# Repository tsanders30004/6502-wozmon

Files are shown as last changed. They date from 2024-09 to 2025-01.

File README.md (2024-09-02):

# 6502 PCB Computer

## INTRODUCTION
- I was in highschool in the eighties when the *home computer revolution* introduced the world to computers running the MOS6502 and Z80 microprocessors.
- My first computer was an Atari 400 which used a 6502.
- When I added two numbers together in BASIC for the first time on that computer, I was hooked.   To this day, I am fascinated with computers.
- I couldn't help feeling nostalgic when I stumbled upon Ben Eater's excellent https://eater.net/6502 webpage, in which he describes how to build a 6502 computer on a breadboard.
- I quickly found out how difficult working with breadboards can be RE: unreliable connections, etc.  One loose wire was all it took to make the computer unusable.
- I therefore abandoned the breadboard altogether and instead decided to build a PCB.
- I had no idea how to do this; I could not even solder.  But I figured all of that out, and eventually I had a PCB that can run *HELLO WORLD* and *WOZMON*.
- This repository has all of the files necessary to build that PCB.

## PCB DESCRIPTION

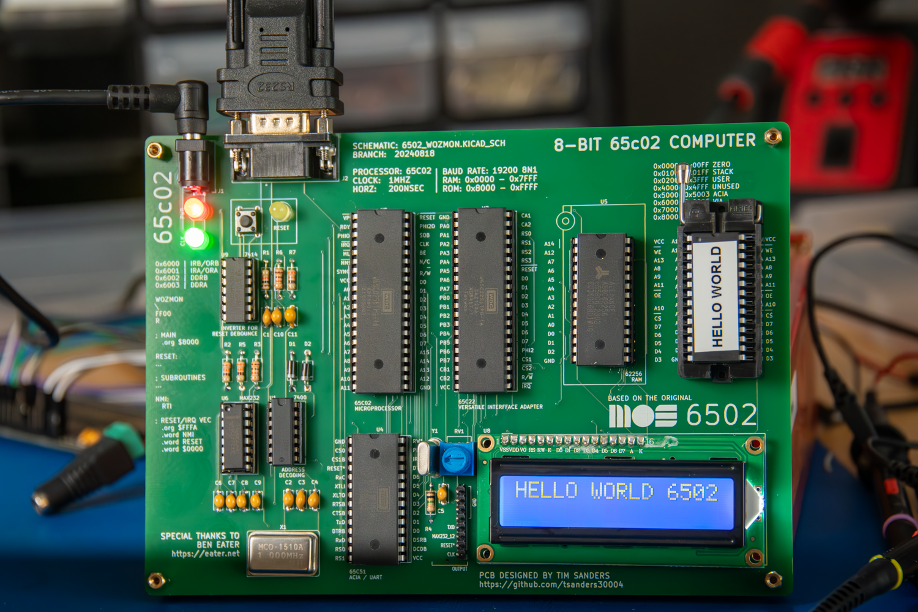
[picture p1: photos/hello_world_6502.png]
Hello World


|General Information||
|-|-|
|Microprocessor|WDC 65c02|
|I/O|65c22|
|UART|65c51|
|Clock|1MHz|
|ROM|32KB|
|RAM|32KB|
|Display|40x2 character LCD|
|Baud Rate|19200 8N1|

The upper left corner of the PCB has ports for +5V (barrel connector) and an RS-232 nine-pin serial cable.  
PWR and CLK LED's will illuminate when power and a clock signal (from the onboard 1MHz clock) are present, respectively.
The PCB can be reset via the RESET button directly below the RS-232 port.  The RESET LED will illuminate when the RESET button is pressed.

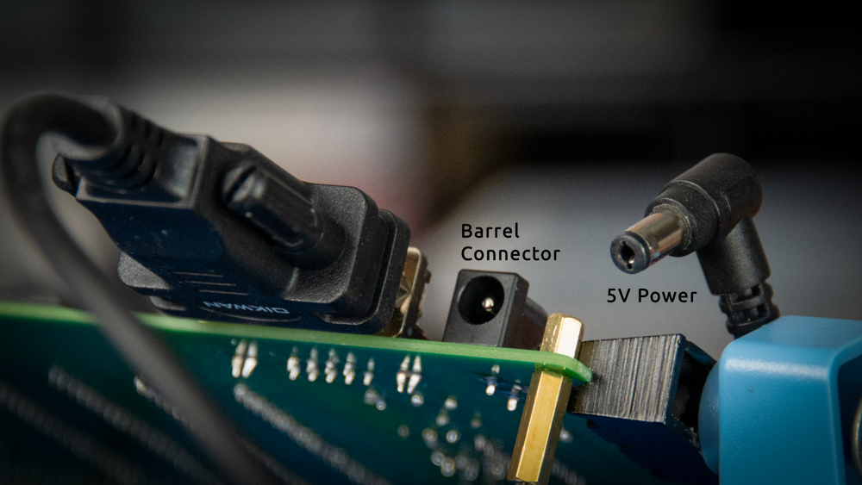
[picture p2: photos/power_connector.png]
Power Connectors


A column of output header pins is positioned immediately to the left of the LCD.  These output pins were primarily used for testing.  The top four pins are for GND.  (I used then when connecting the ground lead of an oscilloscope to the PCB.)  The bottom four pins are TxD, MAX232 pin 12, RESET*, and the CLOCK signal.  You can leave these pins unconnected if you don't want to use them.

## SOFTWARE 

|Filename|Description|
|-|-|
|software/hello/hello.s|'HELLO WORLD 6502' Assembly Code|
|software/hello/hello.out|'HELLO WORLD 6502' ROM file
|software/wozmon/wozmin.s|WOZMON Assembly Code|
|software/wozmon/wozmin.bin|WOZMON ROM file|

The computer *does not run the version of Microsoft BASIC* that Ben describes on his channel.  I have not figured (yet?) why that is so.  But it does run an alternate version of BASIC I found on Github.  See https://github.com/Fifty1Ford/BeEhBasic for more information.

## KICAD FILES

I used KiCad 6 to design the PCB.  
|Filename|Description|
|-|-|
|6502_wozmon.kicad_pro|KiCad 6 Project File|
|6502_wozmon.kicad_sch|KiCad 6 Schematic|
|6502_wozmon.kicad_pcb|KiCad 6 PCB File|
|6502_wozmon.csv|Bill of Materials|
|barrel_jack.pdf|Barrel Jack Power Connector|
|schematic.pdf|Schematic|
|photos/*.png|Photos|
|gerber/*|Gerber Files|

## CLOSING COMMENTS
- I am a hobbyist.  There are no doubt many ways to improve this design.  Feel free to do so! 
- I use a ZIF socket for the ROM chip to make it easier to remove.

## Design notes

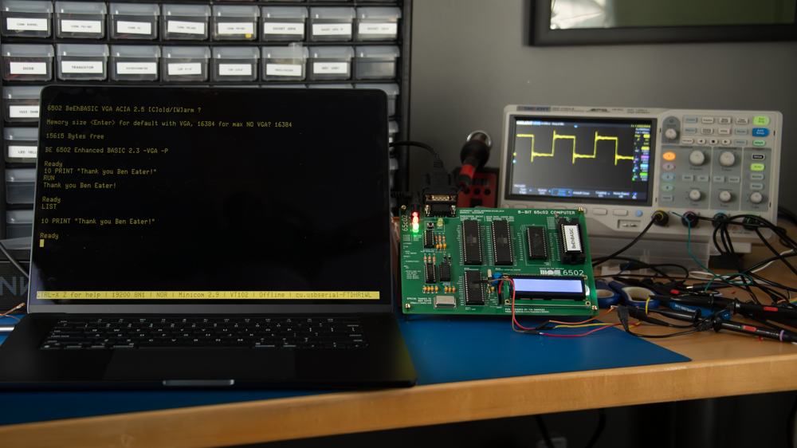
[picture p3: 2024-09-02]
photos/BeEhBASIC.png

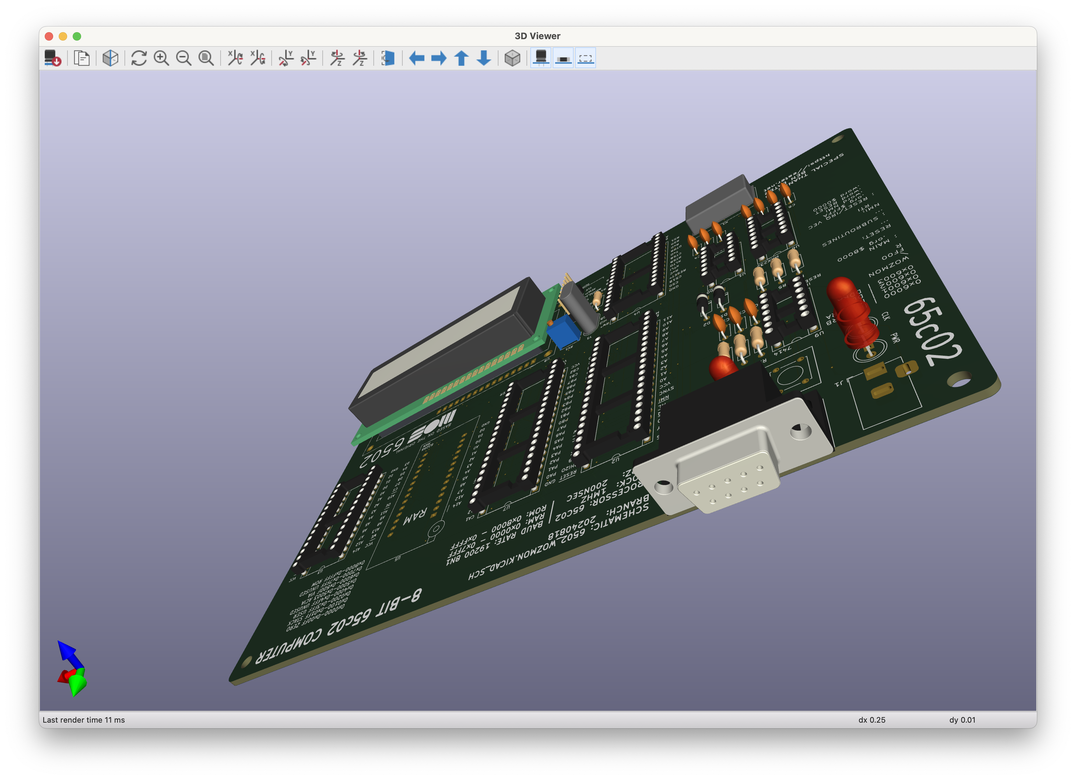
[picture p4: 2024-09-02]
photos/3d_2.png

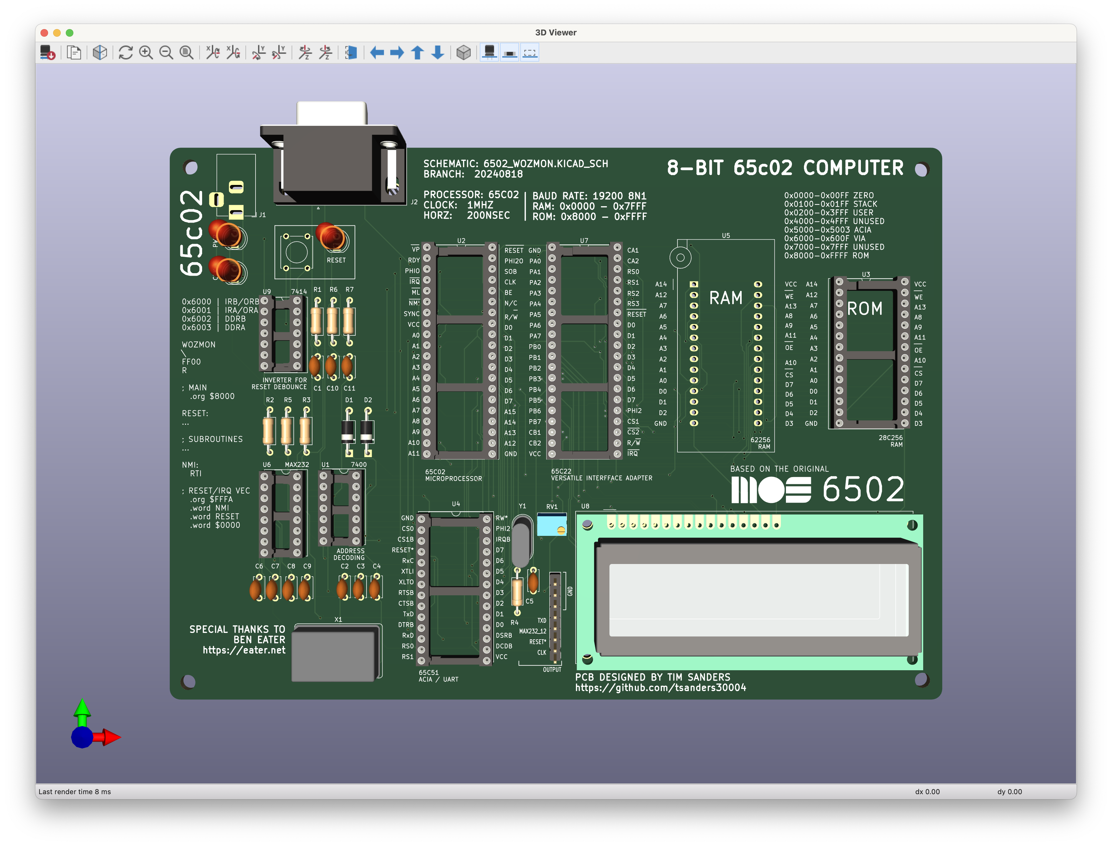
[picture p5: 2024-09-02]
photos/3d_1.png

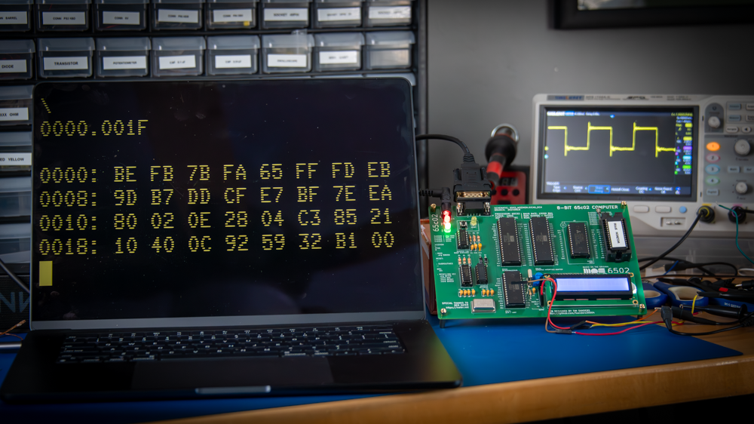
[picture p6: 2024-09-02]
photos/wozmon.png

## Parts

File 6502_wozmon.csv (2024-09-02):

Source: | /Users/tsanders/kicad/6502_wozmon/6502_wozmon.kicad_sch
Date: | 2024-01-21
Tool: | Eeschema (6.0.10-0)
Generator: | /Applications/KiCad/KiCad.app/Contents/SharedSupport/plugins/bom_csv_grouped_by_value_with_fp.py
Component Count: | 39
Ref | Qnty | Value | Cmp name | Footprint | Description | Vendor
C1, C2, C3, C4, C10, | 5 | 0.1u | C | Capacitor_THT:C_Disc_D5.0mm_W2.5mm_P5.00mm | Unpolarized capacitor
C5, | 1 | 20pf | C | Capacitor_THT:C_Disc_D5.0mm_W2.5mm_P5.00mm | Unpolarized capacitor
C6, C7, C8, C9, | 4 | 1uF | C | Capacitor_THT:C_Disc_D5.0mm_W2.5mm_P5.00mm | Unpolarized capacitor
C11, | 1 | 10u | C | Capacitor_THT:C_Disc_D5.0mm_W2.5mm_P5.00mm | Unpolarized capacitor
D1, D2, | 2 | D | D | Diode_THT:D_A-405_P10.16mm_Horizontal | Diode
D3, | 1 | LED | LED | LED_THT:LED_D5.0mm | Light emitting diode
J1, | 1 | Barrel_Jack_Switch_Pin3Ring | Barrel_Jack_Switch_Pin3Ring | Connector_BarrelJack:BarrelJack_Horizontal | DC Barrel Jack with an internal switch
J2, | 1 | DB9_Female | DB9_Female | Connector_Dsub:DSUB-9_Female_Horizontal_P2.77x2.84mm_EdgePinOffset9.90mm_Housed_MountingHolesOffset11.32mm | 9-pin female D-SUB connector
J4, | 1 | Conn_01x08_Male | Conn_01x08_Male | Connector_PinHeader_2.54mm:PinHeader_1x08_P2.54mm_Vertical | Generic connector, single row, 01x08, script generated (kicad-library-utils/schlib/autogen/connector/)
LED_1, LED_2, | 2 | LED | LED | LED_THT:LED_D5.0mm | Light emitting diode
R1, | 1 | 10K | R | Resistor_THT:R_Axial_DIN0207_L6.3mm_D2.5mm_P10.16mm_Horizontal | Resistor
R2, R5, | 2 | 220 | R | Resistor_THT:R_Axial_DIN0207_L6.3mm_D2.5mm_P10.16mm_Horizontal | Resistor
R3, R6, | 2 | 1K | R | Resistor_THT:R_Axial_DIN0207_L6.3mm_D2.5mm_P10.16mm_Horizontal | Resistor
R4, | 1 | 1M | R | Resistor_THT:R_Axial_DIN0207_L6.3mm_D2.5mm_P10.16mm_Horizontal | Resistor
R7, | 1 | 330 | R | Resistor_THT:R_Axial_DIN0207_L6.3mm_D2.5mm_P10.16mm_Horizontal | Resistor
RV1, | 1 | R_Potentiometer | R_Potentiometer | Potentiometer_THT:Potentiometer_Bourns_3266Y_Vertical | Potentiometer
SW2, | 1 | SW_Push_Dual | SW_Push_Dual | Button_Switch_THT:SW_Tactile_Straight_KSA0Axx1LFTR | Push button switch, generic, symbol, four pins
U1, | 1 | 7400 | 7400 | Package_DIP:DIP-14_W7.62mm_Socket | quad 2-input NAND gate
U2, | 1 | W65C02 | W65C02SxP | Package_DIP:DIP-40_W15.24mm_Socket | W65C02S 8-bit CMOS General Purpose Microprocessor, DIP-40
U3, | 1 | 28C256 | 28C256 | Package_DIP:DIP-28_W15.24mm_Socket | Paged Parallel EEPROM 256Kb (32K x 8), DIP-28/SOIC-28
U4, | 1 | W65C51N | W65C51NxP | Package_DIP:DIP-28_W15.24mm_Socket | W65C51N CMOS Asynchronous Communication Interface Adapter (ACIA), Serial UART, DIP-28
U5, | 1 | 62256 | CY62256-70PC | Socket:DIP_Socket-28_W11.9_W12.7_W15.24_W17.78_W18.5_3M_228-1277-00-0602J | 256K (32K x 8) Static RAM, 70ns, DIP-28
U6, | 1 | MAX232 | MAX232 | Package_DIP:DIP-16_W7.62mm_Socket | Dual RS232 driver/receiver, 5V supply, 120kb/s, 0C-70C
U7, | 1 | 65C22 | W65C22SxP | Package_DIP:DIP-40_W15.24mm_Socket | W65C22S CMOS Versatile Interface Adapter (VIA), 20-pin I/O, 2 Timer/Counters, DIP-40
U8, | 1 | WC1602A | WC1602A | Display:WC1602A | LCD 16x2 Alphanumeric , 8 bit parallel bus, 5V VDD
U9, | 1 | 74HC14 | 74HC14 | Package_DIP:DIP-14_W7.62mm_Socket | Hex inverter schmitt trigger
X1, | 1 | GTXO-S14V | GTXO-S14V | Oscillator:Oscillator_DIP-14 | 3.3 & 5V Stratum 3 Sinewave TCXO, DIP14-style metal package
Y1, | 1 | 1.8432MHZ | Crystal | Crystal:Crystal_HC18-U_Vertical | Two pin crystal

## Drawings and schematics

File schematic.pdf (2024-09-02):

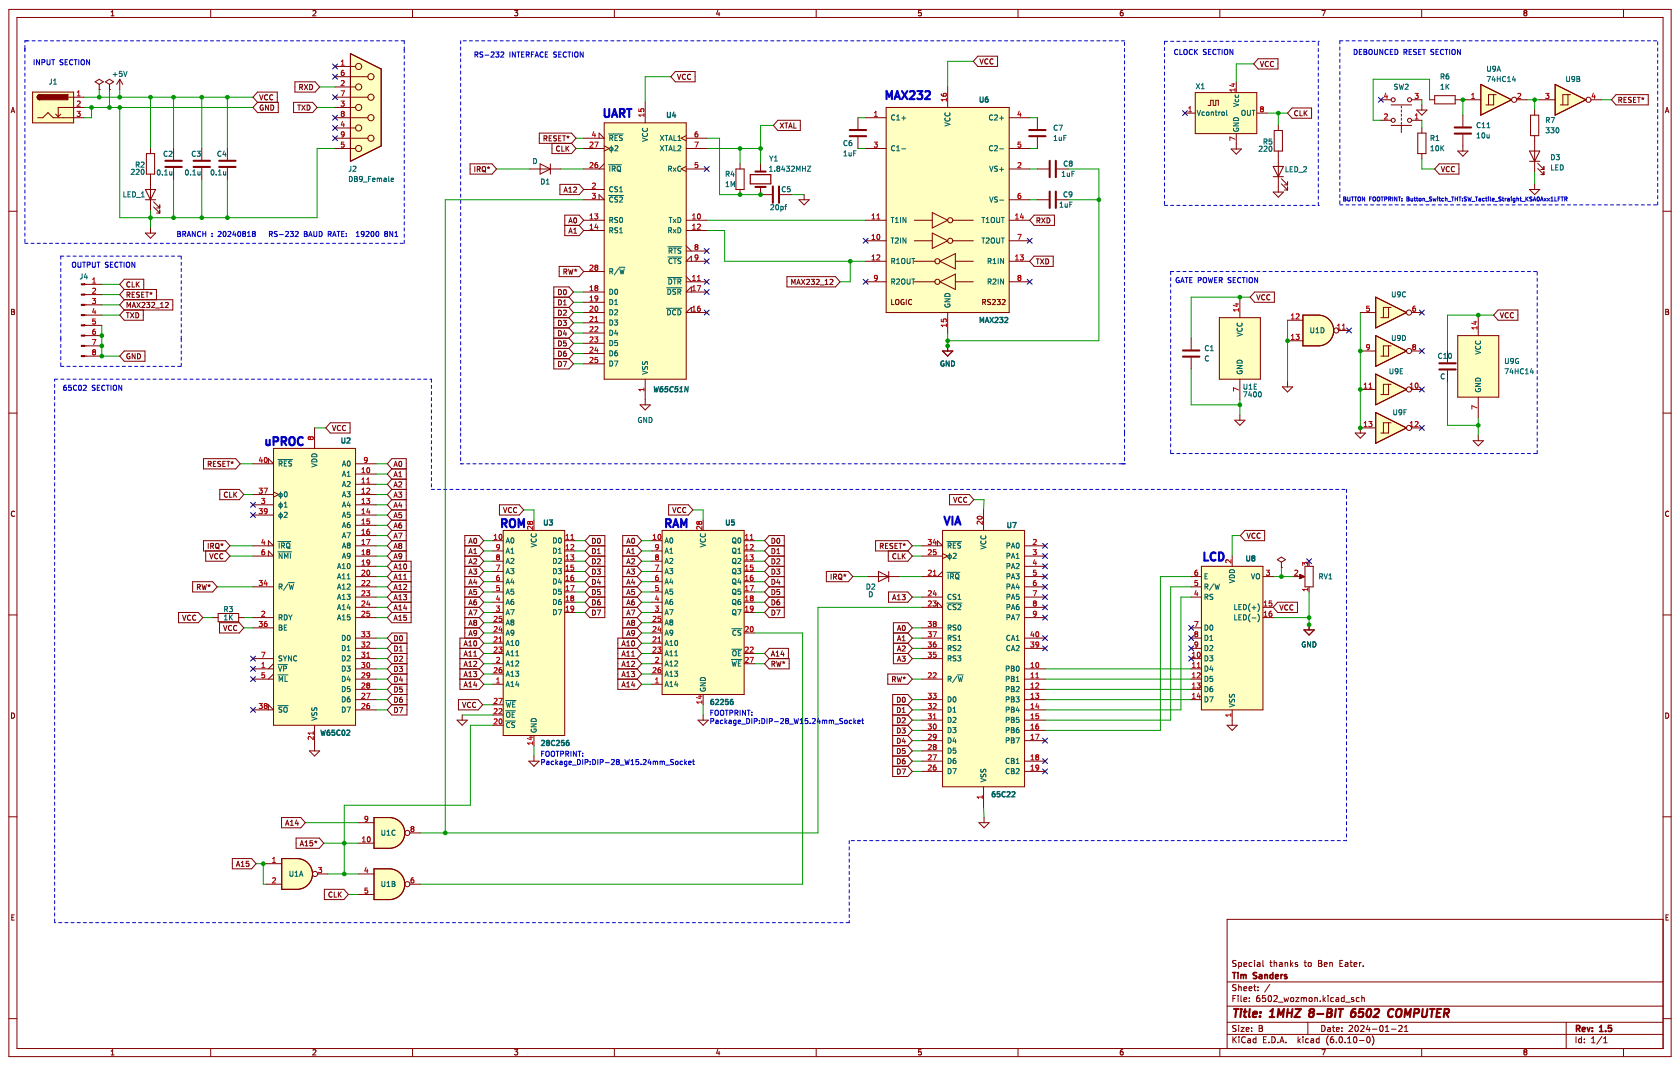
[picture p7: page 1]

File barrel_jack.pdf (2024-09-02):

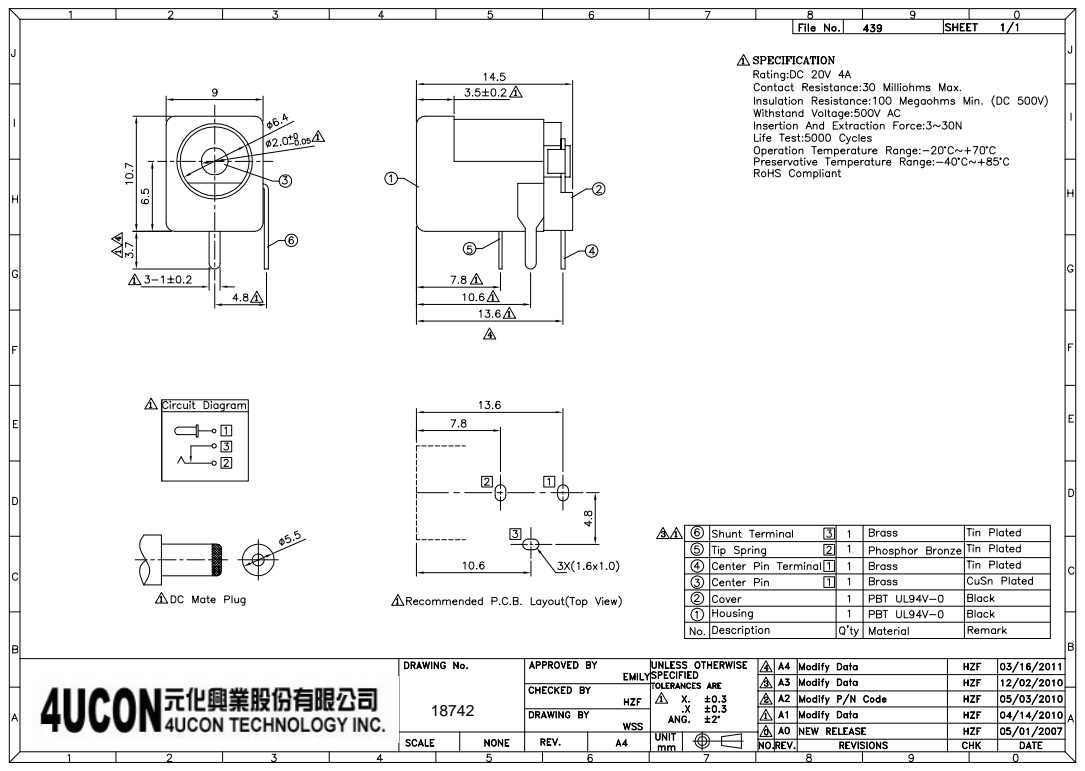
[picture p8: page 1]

## Mouser Electronics

Authorized Distributor

Click to View Pricing, Inventory, Delivery & Lifecycle Information:

SparkFun Electronics: (https://www.mouser.com/sparkfun)

PRT-10811 (https://www.mouser.com/access/?pn=PRT-10811)

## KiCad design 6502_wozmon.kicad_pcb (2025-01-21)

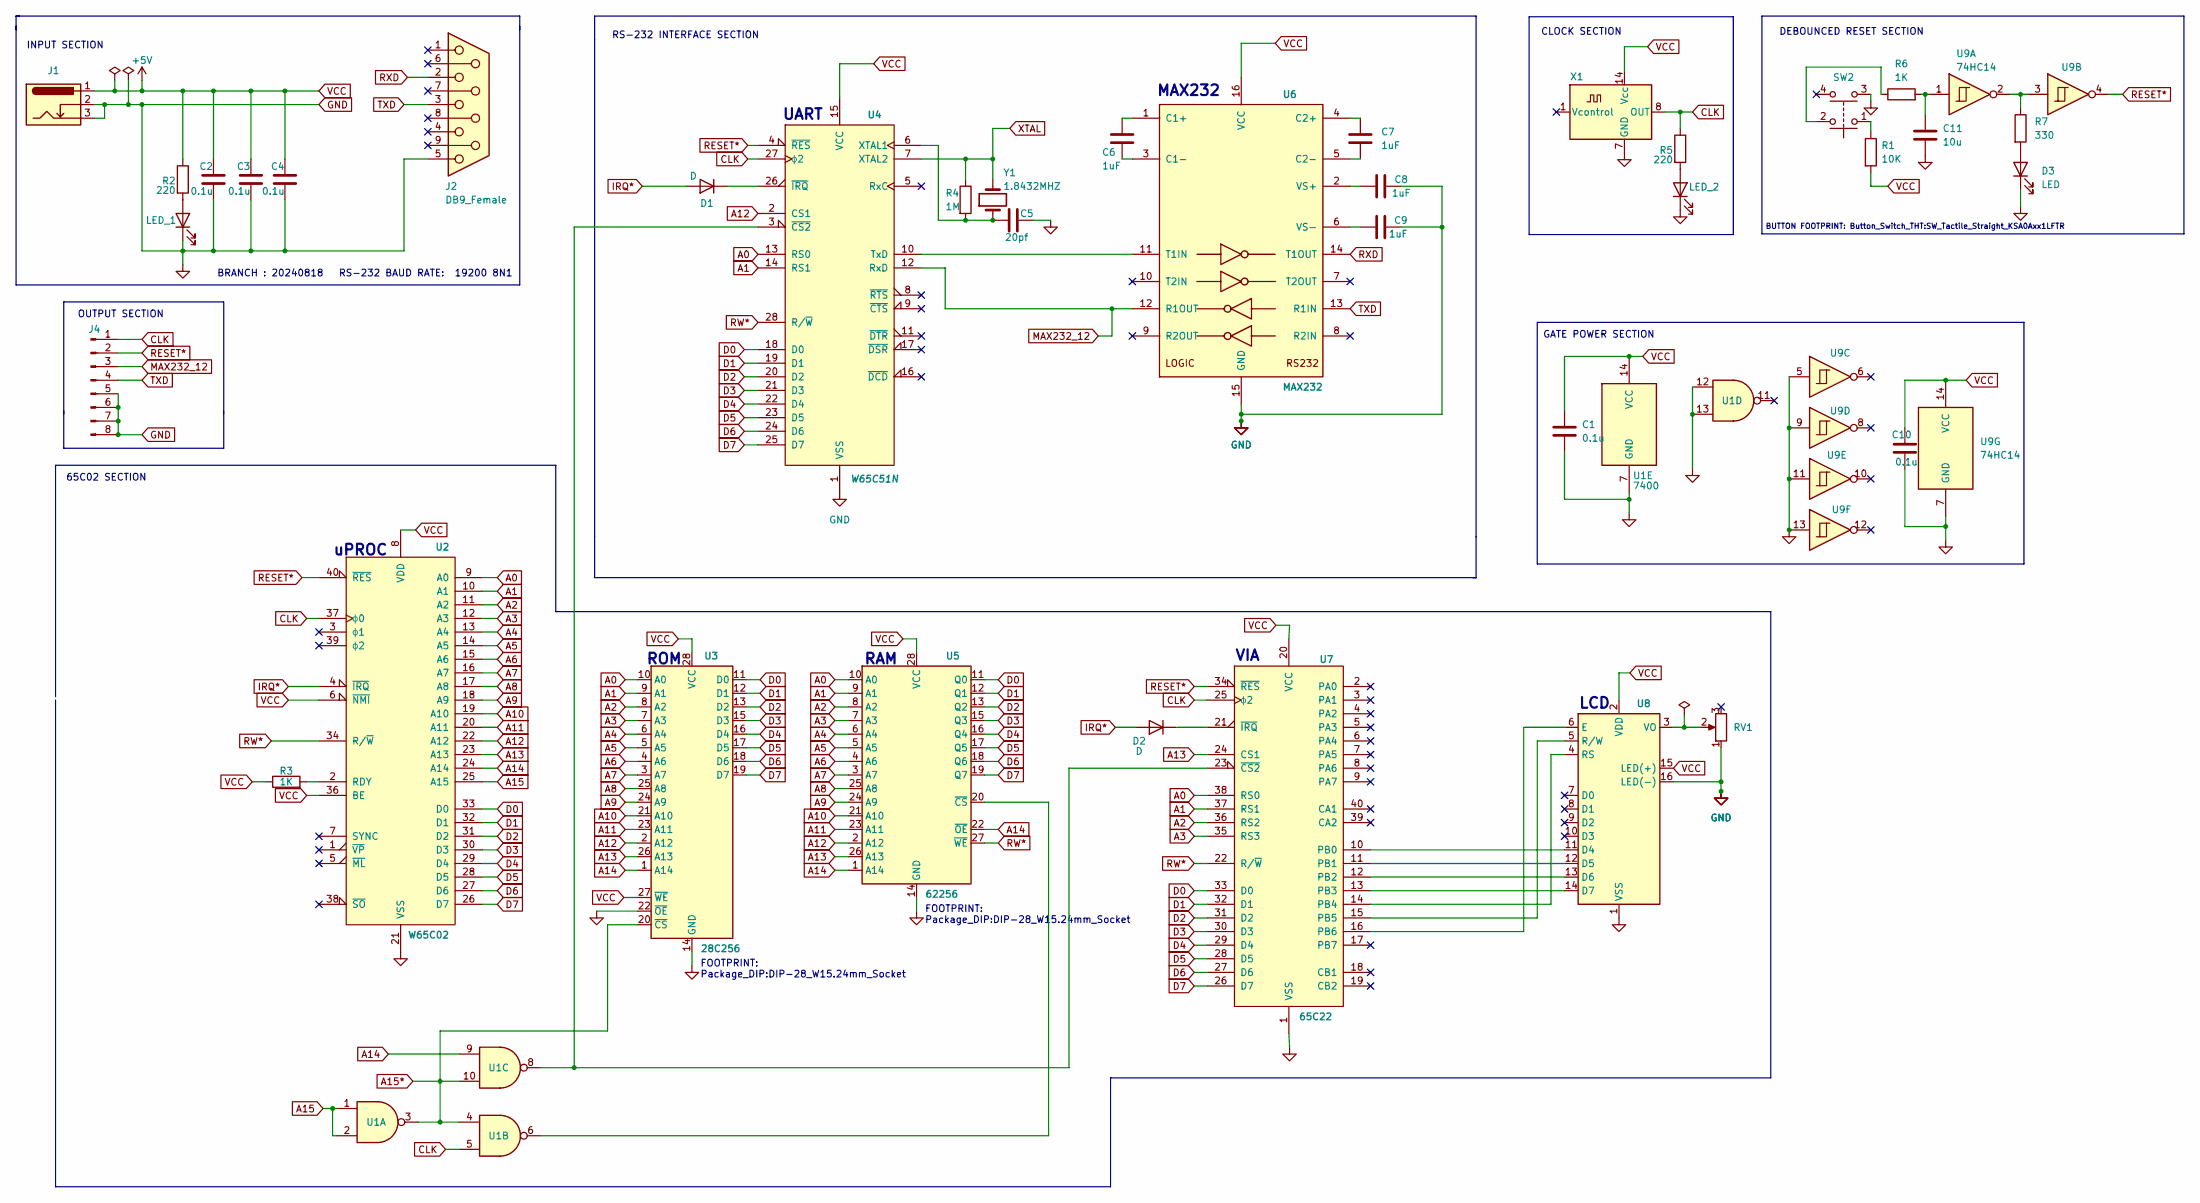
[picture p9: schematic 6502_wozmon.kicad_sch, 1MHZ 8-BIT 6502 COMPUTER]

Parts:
C1, C2, C3, C4, C10: 0.1u; C_Disc_D5.0mm_W2.5mm_P5.00mm
C5: 20pf; C_Disc_D5.0mm_W2.5mm_P5.00mm
C6, C7, C8, C9: 1uF; C_Disc_D5.0mm_W2.5mm_P5.00mm
C11: 10u; C_Disc_D5.0mm_W2.5mm_P5.00mm
D1, D2: D; D_A-405_P10.16mm_Horizontal
D3: LED; LED_D5.0mm
J1: Barrel_Jack_Switch_Pin3Ring; BarrelJack_Horizontal
J2: DB9_Female; DSUB-9_Female_Horizontal_P2.77x2.84mm_EdgePinOffset9.90mm_H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
J4: Conn_01x08_Male; PinHeader_1x08_P2.54mm_Vertical
LED_1, LED_2: LED; LED_D5.0mm
R1: 10K; R_Axial_DIN0207_L6.3mm_D2.5mm_P10.16mm_Horizontal
R2, R5: 220; R_Axial_DIN0207_L6.3mm_D2.5mm_P10.16mm_Horizontal
R3, R6: 1K; R_Axial_DIN0207_L6.3mm_D2.5mm_P10.16mm_Horizontal
R4: 1M; R_Axial_DIN0207_L6.3mm_D2.5mm_P10.16mm_Horizontal
R7: 330; R_Axial_DIN0207_L6.3mm_D2.5mm_P10.16mm_Horizontal
RV1: R_Potentiometer; Potentiometer_Bourns_3266Y_Vertical
SW2: SW_Push_Dual; SW_Tactile_Straight_KSA0Axx1LFTR
U1: 7400; DIP-14_W7.62mm_Socket
U2: W65C02; DIP-40_W15.24mm_Socket
U3: 28C256; DIP-28_W15.24mm_Socket
U4: W65C51N; DIP-28_W15.24mm_Socket
U5: 62256; DIP_Socket-28_W11.9_W12.7_W15.24_W17.78_W18.5_3M_228-1277-0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
U6: MAX232; DIP-16_W7.62mm_Socket
U7: 65C22; DIP-40_W15.24mm_Socket
U8: WC1602A
U9: 74HC14; DIP-14_W7.62mm_Socket
X1: GTXO-S14V; Oscillator_DIP-14
Y1: 1.8432MHZ; Crystal_HC18-U_Vertical

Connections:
A0: U2.9 (A0), U3.10 (A0), U4.13 (RS0), U5.10 (A0), U7.38 (RS0)
A1: U2.10 (A1), U3.9 (A1), U4.14 (RS1), U5.9 (A1), U7.37 (RS1)
A2: U2.11 (A2), U3.8 (A2), U5.8 (A2), U7.36 (RS2)
A3: U2.12 (A3), U3.7 (A3), U5.7 (A3), U7.35 (RS3)
A4: U2.13 (A4), U3.6 (A4), U5.6 (A4)
A5: U2.14 (A5), U3.5 (A5), U5.5 (A5)
A6: U2.15 (A6), U3.4 (A6), U5.4 (A6)
A7: U2.16 (A7), U3.3 (A7), U5.3 (A7)
A8: U2.17 (A8), U3.25 (A8), U5.25 (A8)
A9: U2.18 (A9), U3.24 (A9), U5.24 (A9)
A10: U2.19 (A10), U3.21 (A10), U5.21 (A10)
A11: U2.20 (A11), U3.23 (A11), U5.23 (A11)
A12: U2.22 (A12), U3.2 (A12), U4.2 (CS1), U5.2 (A12)
A13: U2.23 (A13), U3.26 (A13), U5.26 (A13), U7.24 (CS1)
A14: U1.9, U2.24 (A14), U3.1 (A14), U5.1 (A14), U5.22 (~OE)
A15: U1.1, U1.2, U2.25 (A15)
A15*: U1.3, U1.4, U1.10, U3.20 (~CS)
CLK: J4.1, R5.1, U1.5, U2.37 (ϕ0), U4.27 (ϕ2), U7.25 (ϕ2), X1.8 (OUT)
D0: U2.33 (D0), U3.11 (D0), U4.18 (D0), U5.11 (Q0), U7.33 (D0)
D1: U2.32 (D1), U3.12 (D1), U4.19 (D1), U5.12 (Q1), U7.32 (D1)
D2: U2.31 (D2), U3.13 (D2), U4.20 (D2), U5.13 (Q2), U7.31 (D2)
D3: U2.30 (D3), U3.15 (D3), U4.21 (D3), U5.15 (Q3), U7.30 (D3)
D4: U2.29 (D4), U3.16 (D4), U4.22 (D4), U5.16 (Q4), U7.29 (D4)
D5: U2.28 (D5), U3.17 (D5), U4.23 (D5), U5.17 (Q5), U7.28 (D5)
D6: U2.27 (D6), U3.18 (D6), U4.24 (D6), U5.18 (Q6), U7.27 (D6)
D7: U2.26 (D7), U3.19 (D7), U4.25 (D7), U5.19 (Q7), U7.26 (D7)
GND: C1.2, C2.2, C3.2, C4.2, C5.2, C8.1, C9.2, C10.2, C11.2, D3.1 (K), J1.2, J1.3, J2.5, J4.5, J4.6, J4.7, J4.8, LED_1.1 (K), LED_2.1 (K), RV1.1, SW2.3, U1.7 (GND), U1.12, U1.13, U2.21 (VSS), U3.14 (GND), U3.22 (~OE), U4.1 (VSS), U5.14 (GND), U6.15 (GND), U7.1 (VSS), U8.1 (VSS), U8.16 (LED(-)), U9.5, U9.7 (GND), U9.9, U9.11, U9.13, X1.7 (GND)
IRQ*: D1.2 (A), D2.2 (A), U2.4 (~IRQ)
MAX232_12: J4.3, U4.12 (RxD), U6.12 (R1OUT)
unnamed: C5.1, R4.2, U4.6 (XTAL1), Y1.1
unnamed: C6.1, U6.1 (C1+)
unnamed: C6.2, U6.3 (C1-)
unnamed: C7.1, U6.4 (C2+)
unnamed: C7.2, U6.5 (C2-)
unnamed: C8.2, U6.2 (VS+)
unnamed: C9.1, U6.6 (VS-)
unnamed: C11.1, R6.2, U9.1
unnamed: D1.1 (K), U4.26 (~IRQ)
unnamed: D2.1 (K), U7.21 (~IRQ)
unnamed: D3.2 (A), R7.2
unnamed: LED_1.2 (A), R2.2
unnamed: LED_2.2 (A), R5.2
unnamed: R1.1, SW2.1
unnamed: R3.2, U2.2 (RDY)
unnamed: R6.1, SW2.2
unnamed: R7.1, U9.2, U9.3
unnamed: RV1.2, U8.3 (VO)
unnamed: U1.6, U5.20 (~CS)
unnamed: U1.8, U4.3 (~CS2), U7.23 (~CS2)
unnamed: U4.10 (TxD), U6.11 (T1IN)
unnamed: U7.10 (PB0), U8.11 (D4)
unnamed: U7.11 (PB1), U8.12 (D5)
unnamed: U7.12 (PB2), U8.13 (D6)
unnamed: U7.13 (PB3), U8.14 (D7)
unnamed: U7.14 (PB4), U8.4 (RS)
unnamed: U7.15 (PB5), U8.5 (R/W)
unnamed: U7.16 (PB6), U8.6 (E)
RESET*: J4.2, U2.40 (~RES), U4.4 (~RES), U7.34 (~RES), U9.4
RW*: U2.34 (R/~W), U4.28 (R/~W), U5.27 (~WE), U7.22 (R/~W)
RXD: J2.2, U6.14 (T1OUT)
TXD: J2.3, J4.4, U6.13 (R1IN)
VCC: C1.1, C2.1, C3.1, C4.1, C10.1, J1.1, R1.2, R2.1, R3.1, U1.14 (VCC), U2.6 (~NMI), U2.8 (VDD), U2.36 (BE), U3.27 (~WE), U3.28 (VCC), U4.15 (VCC), U5.28 (VCC), U6.16 (VCC), U7.20 (VCC), U8.2 (VDD), U8.15 (LED(+)), U9.14 (VCC), X1.14 (Vcc)
XTAL: R4.1, U4.7 (XTAL2), Y1.2

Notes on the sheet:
FOOTPRINT: Package_DIP:DIP-28_W15.24mm_Socket
UART
OUTPUT SECTION
CLOCK SECTION
65C02 SECTION
INPUT SECTION
MAX232
BRANCH : 20240818
GATE POWER SECTION
ROM
BUTTON FOOTPRINT: Button_Switch_THT:SW_Tactile_Straight_KSA0Axx1LFTR
RAM
uPROC
DEBOUNCED RESET SECTION
RS-232 INTERFACE SECTION
LCD
VIA
RS-232 BAUD RATE: 19200 8N1

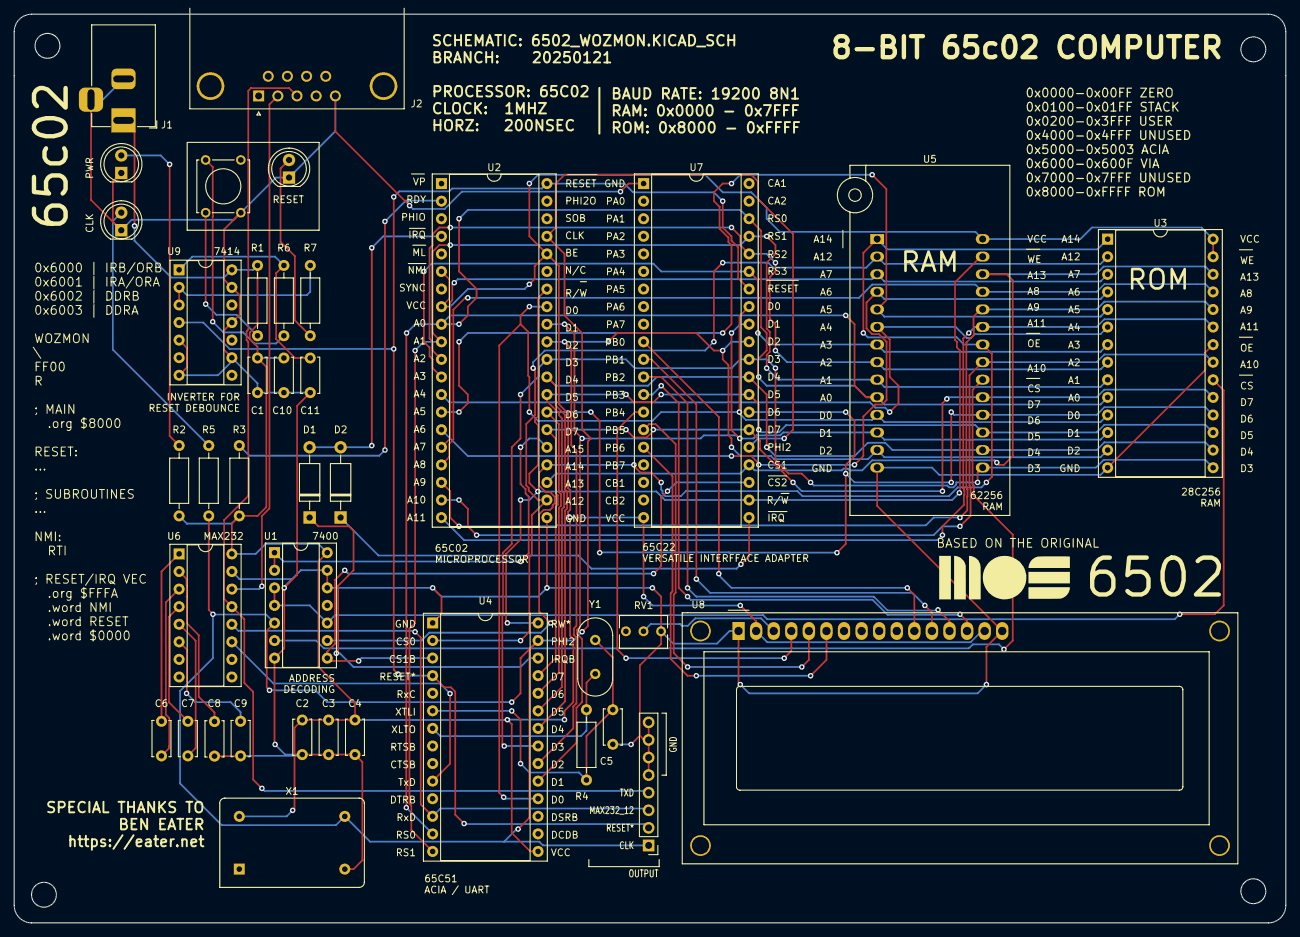
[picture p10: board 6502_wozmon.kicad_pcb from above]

Board: 2 copper layers, 183.7 x 131.3 mm, 39 parts (0 on the bottom side), 63 nets.

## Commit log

2024-07-20 First commit.
    [6502_wozmon.csv, 6502_wozmon.kicad_pcb, 6502_wozmon.kicad_sch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]
2024-07-20 schematic updated to include debounced reset section; added barrel connector.
    [6502_wozmon.kicad_pcb, 6502_wozmon.kicad_sch]
2024-07-21 1. Updated Files A. The pin headers being used as a switch were replaced with a proper button switch and footprint. a. The following were updated: 1. 6502_wozmon.kicad_pcb 2. 6502_wozmon.kicad_prl 2.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
    [6502_wozmon.kicad_pcb, 6502_wozmon.kicad_sch]
2024-08-04 Added gerber files.
    [6502_wozmon-B_Cu.gbr, 6502_wozmon-B_Mask.gbr, 6502_wozmon-B_Paste.gbr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]
2024-09-02 Added README.md, photos, and sotware files.
    [6502_wozmon-B_Cu.gbr, 6502_wozmon-B_Mask.gbr, 6502_wozmon-B_Paste.gbr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]
